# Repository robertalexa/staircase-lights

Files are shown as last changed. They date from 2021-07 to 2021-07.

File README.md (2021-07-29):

# staircase-lights
#### ESP8266 NodeMCU v3 motion activated staircase lights dependant on ambient light and manual control with full RGB and pre-built effects via MQTT as JSON

For my use case, the project allows for:
- Set brightness, RGB colour and pre-built lighting effects via MQTT commands
- OTA updates - upload new firmware via WiFi. The device needs enough memory to store both versions of the firmware for this to work.
- Home Assistant integration - see the yaml file

## Hardware
- nodeMCU v3
- 2 x AM312 PIR
- 1 x Silonex Norps-12 LDR
- 1 x 510 Ohm resistor for the LDR
- 1 x 510 Ohm resistor for the LED Data wire
- 1 x 1000uF capacitor for the power supply, between negative and positive.
- WS2812B LEDs - 480 + 1 sacrificial - 40 per step - 12 steps
- 5V 30A power supply - make sure you get a power supply able to supply the required Amps, plus 20% to allow for good performance. The closer to the limit you use a PSU, the more heat it will generate and the worst performance it will have. In my case I should have gone with a bit bigger but since my LEDs will never run at 100% brightness, they should never consume that much. The formula is no_of_leds x 0.06 = total_amps. Then you need to take into the account the power consumption of the micro controller.
- 18 awg cable
- aluminium profiles with frosted diffusers

## Schematics
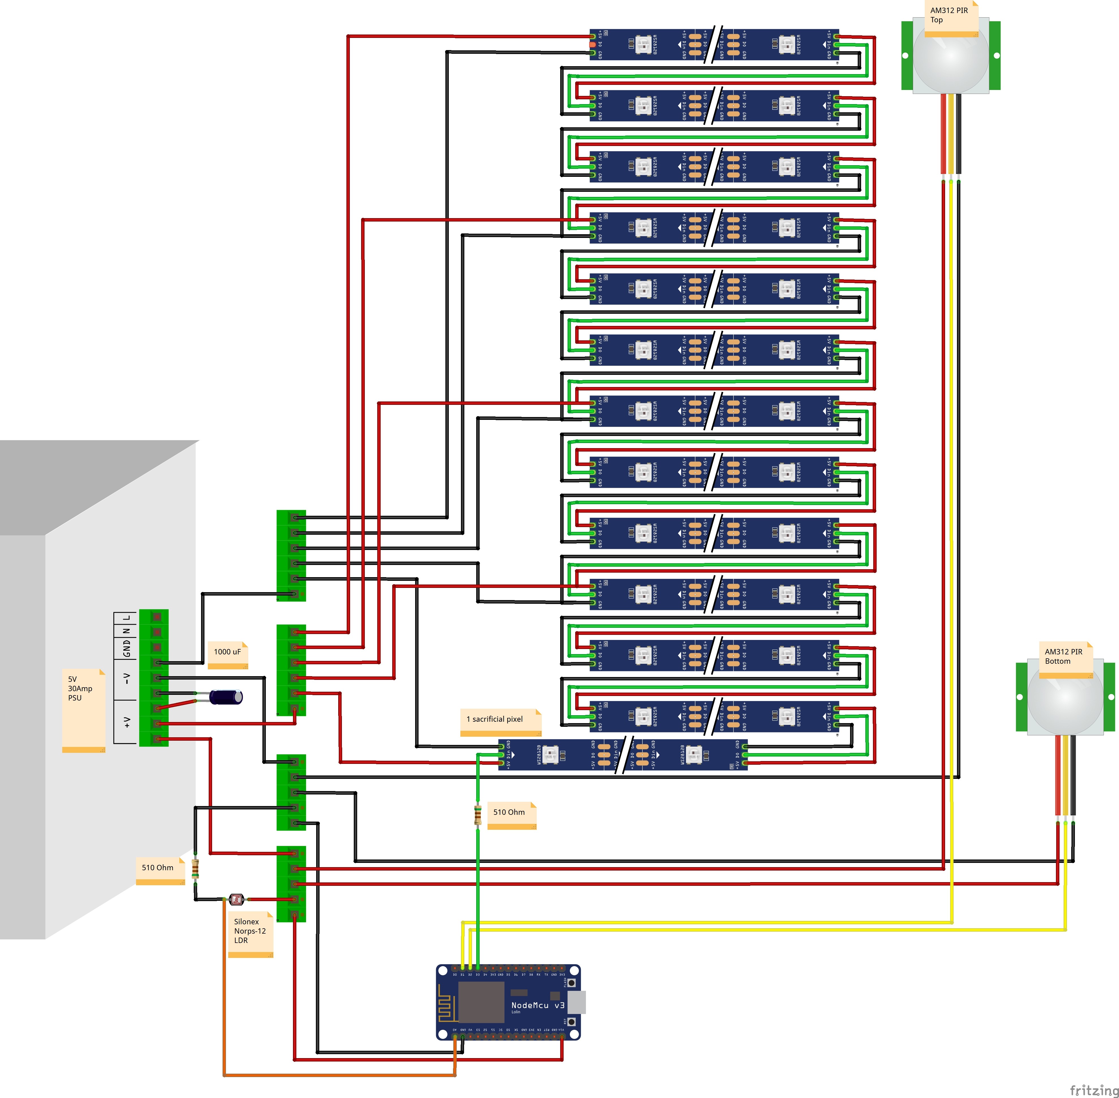
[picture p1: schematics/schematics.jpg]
schematics


## Before you start
1. Rename `secrets.example.h` to `secrets.h` and fill in your credentials
2. Check that the device PINs match your setup
3. Set up the total number of LEDs and number of steps
4. Set up desired starting brightness (can be adjusted via MQTT) as well as motion brightness (can't be adjusted)

## Libraries and versions
At the time of the build the software uses and is compatible with the following:
- ArduinoJson 6.18.0
- PubSubClient 2.8.0
- FastLED 3.4.0

And of course support for ESP8266 - add the following to your board manager
http://arduino.esp8266.com/stable/package_esp8266com_index.json

This will make the following available:
- ESP8266Wifi
- ESP8266mDNS
- WifiUdp
- ArduinoOTA

## Notes
The code contains relics of support for transition, and the HA config for it. I am not using it so I have not tested it. I have however decided to leave it in case I change my mind one day.

## Credits

Original project by @snikogos https://www.instructables.com/LED-Stair-Lighting/

Further adapted for nodeMCU by @daromer2 https://github.com/daromer2/StairLights

More features regarding Home Assistant and effects inspired from @bkpsu https://github.com/bkpsu/ESP-MQTT-JSON-Digital-LEDs which is a fork from @bruhautomation https://github.com/bruhautomation/ESP-MQTT-JSON-Digital-LEDs

## Disclaimer
This is **NOT** a tutorial, this is the code used in my project, as a way for me to store it and remind myself what I've done. Feel free to use it for non-commercial purposes but remember that I take no responsibility for any issues you might encounter, damaged electronics, house electrics etc.

Always be careful when working with electricity, especially with voltage from the mains, if you are uncertain, consult an electrician. Do not endanger yourself or your property.

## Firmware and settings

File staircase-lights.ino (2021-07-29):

/*
    Author: Robert Alexa
    Github: https://github.com/robertalexa
*/

#define FASTLED_INTERRUPT_RETRY_COUNT 0

#include <ArduinoJson.h>
#include <ESP8266WiFi.h>
#include <PubSubClient.h>
#include "FastLED.h"
#include <ESP8266mDNS.h>
#include <WiFiUdp.h>
#include <ArduinoOTA.h>
#include "secrets.h"


/*********************************  MQTT Topics ****************************************/
const char* light_state_topic = "esp/stairs/state";
const char* light_set_topic = "esp/stairs/set";
const char* lwtTopic = "esp/stairs/lwt";


/*******************************  MQTT Definitions *************************************/
const char* on_cmd = "ON";
const char* off_cmd = "OFF";
const char* effect = "solid";
String effectString = "solid";


/*****************************  MQTT JSON Definitions **********************************/
const int BUFFER_SIZE = JSON_OBJECT_SIZE(10);
#define MQTT_MAX_PACKET_SIZE 512


/******************************  FastLED Defintions ************************************/
#define NUM_LEDS    481         // Total number of LEDs 480 + 1 sacrificial
#define DATA_PIN    0           // pin for the NEOPIXEL = D3
#define CHIPSET     WS2812
#define COLOR_ORDER GRB

byte realRed = 0;
byte realGreen = 0;
byte realBlue = 0;

byte red = 255;
byte green = 255;
byte blue = 255;

byte motionBrightness = 25;                         // Adjust LEDs brightness. 0 to 255
byte brightness = 127;
const int steps = 12;                               // Total number of steps 12
const int ledsPerStep = (NUM_LEDS - 1) / steps;     // Total LEDs per step


/*****************************  Sensors Definitions ************************************/
const int pirTop = 5;           // PIR at the top of the staircase = D1
const int pirBottom = 4;        // PIR at the bottom of the staircase = D2
const int ldrSensor = A0;       // LDR Pin = A0

int ledStatus = 0;
int pirTopValue = LOW;          // Variable to hold the PIR status
int pirBottomValue = LOW;       // Variable to hold the PIR status
int ldrSensorValue = 0;         // LDR startup value
int direction = 0;              // Direction of travel; init 0, 1 top to bottom, 2 bottom to top

unsigned long pirTimeout = 60000;  // timestamp to remember when the PIR was triggered.


/*******************************  GLOBALS for FADE *************************************/
bool stateOn = false;
bool startFade = false;
unsigned long lastLoop = 0;
int transitionTime = 0;
int delayMultiplier = 1;
int effectSpeed = 0;
bool inFade = false;
int loopCount = 0;
int stepR, stepG, stepB;
int redVal, grnVal, bluVal;


/*****************************  GLOBALS for EFFECTS ************************************/
//RAINBOW
uint8_t thishue = 0;            // Starting hue value.
uint8_t deltahue = 10;

//CANDYCANE
CRGBPalette16 currentPalettestriped;    //for Candy Cane
CRGBPalette16 HJPalettestriped;         //for Christmas Cane

//NOISE
static uint16_t dist;         // A random number for our noise generator.
uint16_t scale = 30;          // Wouldn't recommend changing this on the fly, or the animation will be really blocky.
uint8_t maxChanges = 48;      // Value for blending between palettes.
CRGBPalette16 targetPalette(OceanColors_p);
CRGBPalette16 currentPalette(CRGB::Black);

//TWINKLE
#define DENSITY     80
int twinklecounter = 0;

//DOTS
uint8_t   count =   0;                                        // Count up to 255 and then reverts to 0
uint8_t fadeval = 224;                                        // Trail behind the LED's. Lower => faster fade.
uint8_t bpm = 30;

//LIGHTNING
uint8_t frequency = 50;                                       // controls the interval between strikes
uint8_t flashes = 8;                                          //the upper limit of flashes per strike
unsigned int dimmer = 1;
uint8_t ledstart;                                             // Starting location of a flash
uint8_t ledlen;
int lightningcounter = 0;

// POLICE
int idex = 0;                //-LED INDEX (0 to NUM_LEDS-1
int TOP_INDEX = int(NUM_LEDS / 2);
int thissat = 255;           //-FX LOOPS DELAY VAR
int antipodal_index(int i) {
    int iN = i + TOP_INDEX;
    if (i >= TOP_INDEX) {
        iN = ( i + TOP_INDEX ) % NUM_LEDS;
    }
    return iN;
}
uint8_t thishuepolice = 0;

//BPM
uint8_t gHue = 0;

//CHRISTMAS ALTERNATE
int toggle = 0;

WiFiClient espClient;
PubSubClient client(espClient);
struct CRGB leds[NUM_LEDS];

// IMPORTANT: To reduce NeoPixel burnout risk, add 1000 uF capacitor across
// pixel power leads, add 300 - 500 Ohm resistor on first pixel's data input
// and minimize distance between Arduino and first pixel.  Avoid connecting
// on a live circuit...if you must, connect GND first.


/********************************** START SETUP *****************************************/
void setup()
{
    delay(3000); // 3 second delay for recovery
    
    Serial.begin(115200);
    Serial.println("Starting up...");

    setup_wifi();
    setup_mqtt();
    setup_ota();

    FastLED.addLeds<CHIPSET, DATA_PIN, COLOR_ORDER>(leds, NUM_LEDS).setCorrection(TypicalLEDStrip);
    FastLED.setBrightness(brightness);
    FastLED.clear();
    FastLED.show();

    setupStripedPalette(CRGB::Red, CRGB::Red, CRGB::White, CRGB::White); //for CANDY CANE
    setupHJPalette(CRGB::Red, CRGB::Red, CRGB::Green, CRGB::Green); //for Holly Jolly

    pinMode(pirTop, INPUT_PULLUP);          // for PIR at top of staircase initialise the input pin and use the internal resistor
    pinMode(pirBottom, INPUT_PULLUP);       // for PIR at bottom of staircase initialise the input pin and use the internal resistor
}


/********************************** START SETUP WIFI *****************************************/
void setup_wifi()
{
    // We start by connecting to a WiFi network
    Serial.println();
    Serial.print("Connecting to ");
    Serial.println(SECRET_WIFI_SSID);

    WiFi.mode(WIFI_STA);
    WiFi.begin(SECRET_WIFI_SSID, SECRET_WIFI_PASS);

    while (WiFi.status() != WL_CONNECTED) {
        delay(500);
        Serial.print(".");
    }

    Serial.println("");
    Serial.println("WiFi connected");
    Serial.println("IP address: ");
    Serial.println(WiFi.localIP());
}


/********************************** START SETUP MQTT *****************************************/
void setup_mqtt()
{
    client.setServer(SECRET_MQTT_IP, SECRET_MQTT_PORT);
    client.setCallback(callback);

    // Loop until we're connected
    while (!client.connected()) {
        Serial.println("");
        Serial.println("Attempting MQTT connection...");
        // Attempt to connect
        if (client.connect(SECRET_DEVICE, SECRET_MQTT_USER, SECRET_MQTT_PASS, lwtTopic, 0, 1, "offline")) {
            Serial.println("MQTT connected");
            client.subscribe(light_set_topic);
            client.publish(lwtTopic, "online", true);
            client.publish(light_state_topic, "off");
            setColor(0, 0, 0);
            sendState();
        } else {
            Serial.print("failed, rc=");
            Serial.print(client.state());
            Serial.println(" try again in 5 seconds");
            // Wait 5 seconds before retrying
            delay(5000);
        }
    }
}


/********************************** START SETUP OAT *****************************************/
void setup_ota()
{
    ArduinoOTA.setPort(SECRET_OTA_PORT);
    // Hostname defaults to esp8266-[ChipID]
    ArduinoOTA.setHostname(SECRET_DEVICE);

    // No authentication by default
    ArduinoOTA.setPassword((const char *)SECRET_OTA_PASS);

    ArduinoOTA.onStart([]() {
        Serial.println("Starting");
    });
    ArduinoOTA.onEnd([]() {
        Serial.println("\nEnd");
    });
    ArduinoOTA.onProgress([](unsigned int progress, unsigned int total) {
        Serial.printf("Progress: %u%%\r", (progress / (total / 100)));
    });
    ArduinoOTA.onError([](ota_error_t error) {
        Serial.printf("Error[%u]: ", error);
        if (error == OTA_AUTH_ERROR) {
            Serial.println("Auth Failed");
        } else if (error == OTA_BEGIN_ERROR) {
            Serial.println("Begin Failed");
        } else if (error == OTA_CONNECT_ERROR) {
            Serial.println("Connect Failed");
        } else if (error == OTA_RECEIVE_ERROR) {
            Serial.println("Receive Failed");
        } else if (error == OTA_END_ERROR) {
            Serial.println("End Failed");
        }
    });
    ArduinoOTA.begin();
}

/*
    SAMPLE PAYLOAD:
    {
    "brightness": 120,
    "color": {
      "r": 255,
      "g": 100,
      "b": 100
    },
    "transition": 5,
    "state": "ON"
    }
*/


/********************************** START CALLBACK*****************************************/
void callback(char* topic, byte* payload, unsigned int length)
{
    Serial.print("Message arrived [");
    Serial.print(topic);
    Serial.print("] ");

    char message[length + 1];
    for (int i = 0; i < length; i++) {
        message[i] = (char)payload[i];
    }
    message[length] = '\0';
    Serial.println(message);

    if (!processJson(message)) {
        return;
    }

    if (stateOn) {
        realRed = map(red, 0, 255, 0, brightness);
        realGreen = map(green, 0, 255, 0, brightness);
        realBlue = map(blue, 0, 255, 0, brightness);
    } else {
        realRed = 0;
        realGreen = 0;
        realBlue = 0;
    }

    Serial.println(effect);

    startFade = true;
    inFade = false; // Kill the current fade

    sendState();
}


/********************************** START PROCESS JSON*****************************************/
bool processJson(char* message)
{
    StaticJsonDocument<BUFFER_SIZE> doc;

    DeserializationError error = deserializeJson(doc, message);

    if (error) {
        Serial.print("deserializeJson() failed with code ");
        Serial.println(error.c_str());
        return false;
    }

    if (doc.containsKey("state")) {
        if (strcmp(doc["state"], on_cmd) == 0) {
            stateOn = true;
        } else if (strcmp(doc["state"], off_cmd) == 0) {
            stateOn = false;
        }
    }

    if (doc.containsKey("color")) {
        red = doc["color"]["r"];
        green = doc["color"]["g"];
        blue = doc["color"]["b"];
    }

    if (doc.containsKey("brightness")) {
        brightness = doc["brightness"];
    }

    if (doc.containsKey("effect")) {
        effect = doc["effect"];
        effectString = effect;
        twinklecounter = 0; //manage twinklecounter
    }

    if (doc.containsKey("transition")) {
        transitionTime = doc["transition"];
    } else if ( effectString == "solid") {
        transitionTime = 0;
    }

    return true;
}


/********************************** START SEND STATE*****************************************/
void sendState()
{
    StaticJsonDocument<BUFFER_SIZE> doc;

    doc["state"] = (stateOn) ? on_cmd : off_cmd;
    JsonObject color = doc.createNestedObject("color");
    color["r"] = red;
    color["g"] = green;
    color["b"] = blue;

    doc["brightness"] = brightness;
    doc["effect"] = effectString.c_str();
    doc["transition"] = transitionTime;

    size_t docSize = measureJson(doc)+1;
    char buffer[docSize];

    serializeJson(doc, buffer, docSize);

    client.publish(light_state_topic, buffer, true);
}


/********************************** START Set Color*****************************************/
void setColor(int inR, int inG, int inB)
{
    for (int i = 0; i < NUM_LEDS; i++) {
        leds[i].red   = inR;
        leds[i].green = inG;
        leds[i].blue  = inB;
    }

    FastLED.show();

    Serial.println("Setting LEDs:");
    Serial.print("r: ");
    Serial.print(inR);
    Serial.print(", g: ");
    Serial.print(inG);
    Serial.print(", b: ");
    Serial.println(inB);
}


/********************************** START MAIN LOOP*****************************************/
void loop()
{
    if (WiFi.status() != WL_CONNECTED) {
        delay(1);
        Serial.print("WIFI Disconnected. Attempting reconnection.");
        setup_wifi();
        return;
    }

    if (!client.connected()) {
        delay(1);
        Serial.print("MQTT Disconnected...");
        setup_mqtt();
        return;
    }

    client.loop();

    ArduinoOTA.handle();

    // Manual LEDs control via MQTT
    if (stateOn) {
        FastLED.setBrightness(brightness);
        effects();
        delay(10);
        return;
    }

    // Motion Lights - only get here if stateOn is false (e.g no manual colour/effect)
    showleds();

    // Constantly poll the sensors
    pirTopValue = digitalRead(pirTop);
    pirBottomValue = digitalRead(pirBottom);
    ldrSensorValue = analogRead(ldrSensor);
    
    if ((pirTopValue == HIGH || pirBottomValue == HIGH) && ldrSensorValue < 30) { // Motion and Darkness
        pirTimeout = millis(); // Timestamp when the PIR was triggered.
        if (pirTopValue == HIGH && direction != 2) { // the 2nd term allows pirTimeout to be constantly reset if one lingers at the top of the staircase before decending but will not allow the bottom PIR to reset pirTimeout as you descend past it.
            direction = 1;
            if (ledStatus == 0) {
                // lights up the strip from top to bottom
                Serial.println("Top PIR motion detected");
                colourTopToBottom(255, 131, 40, 100);      // Warm White
                ledStatus = 1;
            }
        }
        if (pirBottomValue == HIGH && direction != 1) { // the 2nd term allows pirTimeout to be constantly reset if one lingers at the bottom of the staircase before ascending but will not allow the top PIR to reset pirTimeout as you ascent past it.
            direction = 2;
            if (ledStatus == 0) {
                // lights up the strip from bottom to top
                Serial.println ("Bottom PIR motion detected");
                colourBottomToTop(255, 131, 40, 100);      // Warm White
                ledStatus = 1;
            }
        }
    }
    
    if (pirTimeout + 4000 < millis() && direction > 0) { //switch off LEDs in the direction of travel.
        if (direction == 1) {
            colourTopToBottom(0, 0, 0, 50); // Off
        }
        if (direction == 2) {
            colourBottomToTop(0, 0, 0, 50); // Off
        }
        direction = 0;
        ledStatus = 0;
    }

    delay(10);
}

// Fade light each step strip
void colourTopToBottom(int inR, int inG, int inB, uint16_t wait)
{
    for (uint16_t j = steps; j > 0; j--) {
        int start = ledsPerStep * j + 1;                            // starting LED per step basis
        for (uint16_t i = start; i >= start - ledsPerStep; i--) {    // loop LEDs on this step
            leds[i - 1].red   = inR;
            leds[i - 1].green = inG;
            leds[i - 1].blue  = inB;
        }
        leds[0].setRGB( 0, 0, 0);
        FastLED.setBrightness(motionBrightness);
        FastLED.show();
        delay(wait);
    }
}

void colourBottomToTop(int inR, int inG, int inB, uint16_t wait)
{
    for (uint16_t j = 0; j < steps; j++) {
        int start = ledsPerStep * j + 1;                            // starting LED per step basis
        for (uint16_t i = start; i <= start + ledsPerStep; i++) {    // loop LEDs on this step
            leds[i - 1].red   = inR;
            leds[i - 1].green = inG;
            leds[i - 1].blue  = inB;
        }
        leds[0].setRGB( 0, 0, 0);
        FastLED.setBrightness(motionBrightness);
        FastLED.show();
        delay(wait);
    }
}
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

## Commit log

2021-07-01 Replace adafruit with fast leds, add support for HA Light entity - major rewrite
    [staircase-lights.ino]
2021-07-01 Fix issue with resetting the lights
    [staircase-lights.ino]
2021-07-01 Move effects into a separate function and work on resetting the pixels before motion
    [staircase-lights.ino]
2021-07-10 Change all effects to respect MQTT brightness. Fix issue with brightness not being what HA says
    [staircase-lights.ino]
2021-07-18 Add schematics
    [schematics.fzz]
2021-07-18 Add schematic to README.md
2021-07-29 Update schematics
    [schematics.fzz]
2021-07-29 Turn off all LEDs on startup
2021-07-29 Fix mistake with toptobottom
    [staircase-lights.ino]
